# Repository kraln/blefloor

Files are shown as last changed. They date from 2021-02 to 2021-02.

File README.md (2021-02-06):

# BLEFloor

BLEFloor is an Arduino-powered WIFI/BLE connected thermostat 

## Warning

This hardware device is designed to switch/engage household voltages (100-230VAC). It has not been formally tested in any lab, nor does it carry any safety certification. While many precautions have been taken, always be careful around dangerous electricity as it is deadly and can kill you or others. In many jurisdictions, only electricians are allowed to connect to household voltages. Your mileage may vary, be careful!

## Hardware Description

The main controller is an Arduino Nano 33 IoT, which has an Atmel ARM Microcontroller attached to a uBlox Nina Wifi/BLE module (itself an ESP of some sort). A SI7020-A20 temperature/humidity sensor from Silicon Labs is attached, as well as a TPL5010 watchdog. The powersupply is a monolithic block from RECOM, the relay is from Omron, and the power path is fused and tranzorbed. 

### Theory of operation

A heated floor is controlled by a wax valve which melts over five minutes in the presence of heat. A heated floor thermostat is a bimetallic strip which can engage or disengage at a specific temperature. This device replaces the bimetallic strip with connected logic, such that it can be configured on a schedule, controlled remotely, make reports, etc. 

### Pictures

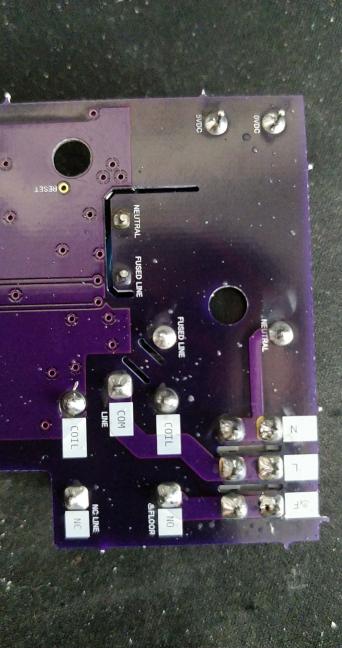
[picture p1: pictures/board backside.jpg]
Board Backside

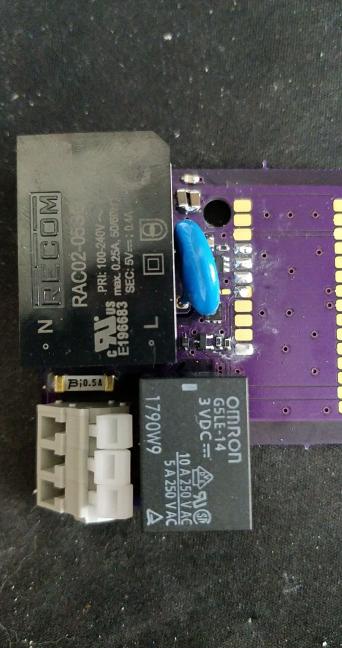
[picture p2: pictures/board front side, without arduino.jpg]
Board Front, No Arduino


### Errata

The temperature sensor is not sufficiently isolated from the operating conditions of the board and as such when the relay is engaged it senses a 2-3 degree self-warming. This is currently compensated for in the firmware.

## Firmware description

The firmware is written using a recent Arduino IDE. 

The setup() function initializes the GPIO pins, sets up an interrupt handler for the watchdog, sets up I2C for the temperature sensor, and initializes communications with the NINA module.

Configuration settings are saved in a file on the NINA module, this requires the firmware on the NINA module to be updated to a recent release (tested with 1.4.3). The contents of the configuration are in the settings_t struct. The first-run defaults are defined in the defaults() function.

The main loop() function checks to see if the watchdog chip activated, and if so reads the current temperature and humity. If configured, these values are reported to an InfluxDB UDP collector. The remote firmware update query is serviced, the HTTP handler is serviced, and the heartbeat LED is serviced.

If rip and rport are configured, the device will report the current temperature, relative humidity, if the relay is engaged, and when it has rebooted over UDP.

The HTTP handler listens for GET and POST requests. GET requests bring up a simple page with the current state of the device, whereas POST accepts the following commands in a query string:

| command | argument | comment |
| --- | --- | --- |
| ssid | wifi ssid to connect to | max length = 32 characters | 
| pass | password for wifi | max length = 32 characters |
| title | device name | max length = 32 characters |
| rip | reporting ip | address of influxdb in dotted format, max length 16 characters (though it should always fit in 13) | 
| rport | reporting port | port for influxdb udp |
| on | temperature in celcius below which the relay will engage | accepts numbers down to 5.0, anything beneath 5.0 will be raised to 5.0 |
| off | temperature in celcius above which the relay will disenage | accepts up to 50.0, anything above will be dropped to 50.0 |
| to | temperature offset | in case the reading differs from the actual room temperature, this will be applied before any other logic |
| save | n/a | instruct the thermostat to save the current configuration (must be last) |
| reset | n/a | instruct the thermostat to reboot | 
| relay | off/on | force the relay to (dis)engage |

Example Setting Config:

`   
  curl --data "ssid=My Access Point&pass=password!&rip=192.168.178.72&save=yes" 192.168.178.45
`  

### Pictures

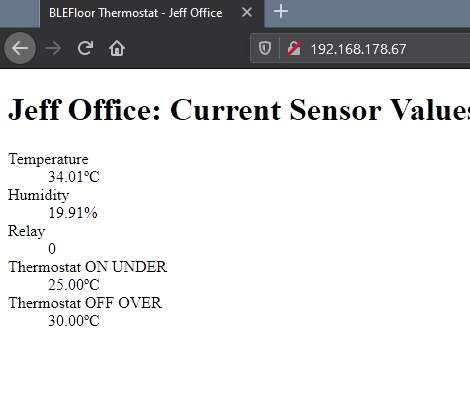
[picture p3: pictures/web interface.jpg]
Web Interface


### Errata

## Contributing
Pull requests are welcome. For major changes, please open an issue first to discuss what you would like to change.

## License
Firmware:
[MPLv2](https://choosealicense.com/licenses/mpl-2.0/)

Hardware design files:
[CC BY-SA 4.0](https://creativecommons.org/licenses/by-sa/4.0/)

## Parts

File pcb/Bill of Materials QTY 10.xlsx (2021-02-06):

Designator | Comment | Manufacturer 1 | Manufacturer Part Number 1 | Quantity | Supplier 1 | Supplier Part Number 1
C1, C2 | 4.7uF | Murata (https://octopart-clicks.com/click/altium?sku=81-GCM31CC71H475MA3K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) | GCM31CC71H475MA03K (https://octopart-clicks.com/click/altium?sku=81-GCM31CC71H475MA3K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) | 2 | Mouser | 81-GCM31CC71H475MA3K (https://octopart-clicks.com/click/altium?sku=81-GCM31CC71H475MA3K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) | 20
C3, C4, C5 | Cap Semi | Kyocera AVX (https://octopart-clicks.com/click/altium?sku=581-08055C104K4Z2A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) | 08055C104K4Z2A/4K (https://octopart-clicks.com/click/altium?sku=581-08055C104K4Z2A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) | 3 | Mouser | 581-08055C104K4Z2A (https://octopart-clicks.com/click/altium?sku=581-08055C104K4Z2A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) | 30
D1 | D Zener | Philips (https://octopart-clicks.com/click/altium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) | BZX384-B3V3,115 (https://octopart-clicks.com/click/altium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) | 1 | Mouser | 771-BZX384-B3V3-T/R (https://octopart-clicks.com/click/altium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) | 10
D2 | RELAY_EN | Stanley Electric (https://octopart-clicks.com/click/altium?manufacturer=Stanley%20Electric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) | SJW1151CKS-100-TR (https://octopart-clicks.com/click/altium?manufacturer=Stanley%20Electric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) | 1 | Mouser | 327-SJW1151CKS100TR (https://octopart-clicks.com/click/altium?manufacturer=Stanley%20Electric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) | 10
F1 | Fuse 1 | Bourns (https://octopart-clicks.com/click/altium?sku=652-SF-3812TL050T-2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) | SF-3812TL050T-2 (https://octopart-clicks.com/click/altium?sku=652-SF-3812TL050T-2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) | 1 | Mouser | 652-SF-3812TL050T-2 (https://octopart-clicks.com/click/altium?sku=652-SF-3812TL050T-2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) | 10
J1 | PTB Header | CUI Devices (https://octopart-clicks.com/click/altium?manufacturer=CUI%20Devices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) | TBL005A-500-03GY-2WT (https://octopart-clicks.com/click/altium?manufacturer=CUI%20Devices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) | 1 | Mouser | 490-TBL05A50003GY2WT (https://octopart-clicks.com/click/altium?manufacturer=CUI%20Devices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) | 10
K1 | Power Relay | Omron (https://octopart-clicks.com/click/altium?sku=653-G5LE-14DC3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) | G5LE-14-DC3 (https://octopart-clicks.com/click/altium?sku=653-G5LE-14DC3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) | 1 | Mouser | 653-G5LE-14DC3 (https://octopart-clicks.com/click/altium?sku=653-G5LE-14DC3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) | 10
MOV | Tranzorb | Bourns (https://octopart-clicks.com/click/altium?sku=652-MOV-14D391K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) | MOV-14D391K (https://octopart-clicks.com/click/altium?sku=652-MOV-14D391K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) | 1 | Mouser | 652-MOV-14D391K (https://octopart-clicks.com/click/altium?sku=652-MOV-14D391K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) | 10
Q1 | QNPN | Diodes (https://octopart-clicks.com/click/altium?sku=621-BC847A-7-F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) | BC847A-7-F (https://octopart-clicks.com/click/altium?sku=621-BC847A-7-F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) | 1 | Mouser | 621-BC847A-7-F (https://octopart-clicks.com/click/altium?sku=621-BC847A-7-F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) | 10
R1 | Res3 | Panasonic (https://octopart-clicks.com/click/altium?sku=667-ERJ-3EKF1001V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) | ERJ3EKF1001V (https://octopart-clicks.com/click/altium?sku=667-ERJ-3EKF1001V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) | 1 | Mouser | 667-ERJ-3EKF1001V (https://octopart-clicks.com/click/altium?sku=667-ERJ-3EKF1001V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) | 10
R2, R3, R4, R5 | Res3 | Panasonic (https://octopart-clicks.com/click/altium?sku=667-ERJ-3EKF1002V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) | ERJ-3EKF1002V (https://octopart-clicks.com/click/altium?sku=667-ERJ-3EKF1002V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) | 4 | Mouser | 667-ERJ-3EKF1002V (https://octopart-clicks.com/click/altium?sku=667-ERJ-3EKF1002V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) | 40
U0 | MCU | Arduino | Arduino Nano 33 IoT | 1 |  |  | 10
U1 | AC/DC 2W | Recom (https://octopart-clicks.com/click/altium?sku=919-RAC02-05SGA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) | RAC02-05SGA (https://octopart-clicks.com/click/altium?sku=919-RAC02-05SGA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) | 1 | Mouser | 919-RAC02-05SGA (https://octopart-clicks.com/click/altium?sku=919-RAC02-05SGA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) | 10
U2 | Watchdog | Texas Instruments (https://octopart-clicks.com/click/altium?sku=595-TPL5010DDCR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) | TPL5010DDCR (https://octopart-clicks.com/click/altium?sku=595-TPL5010DDCR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) | 1 | Mouser | 595-TPL5010DDCR (https://octopart-clicks.com/click/altium?sku=595-TPL5010DDCR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) | 10
U3 | Temp and Humidity Sensor | Silicon Labs (https://octopart-clicks.com/click/altium?sku=634-SI7020-A20-GM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) | SI7020-A20-GM (https://octopart-clicks.com/click/altium?sku=634-SI7020-A20-GM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) | 1 | Mouser | 634-SI7020-A20-GM (https://octopart-clicks.com/click/altium?sku=634-SI7020-A20-GM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) | 10

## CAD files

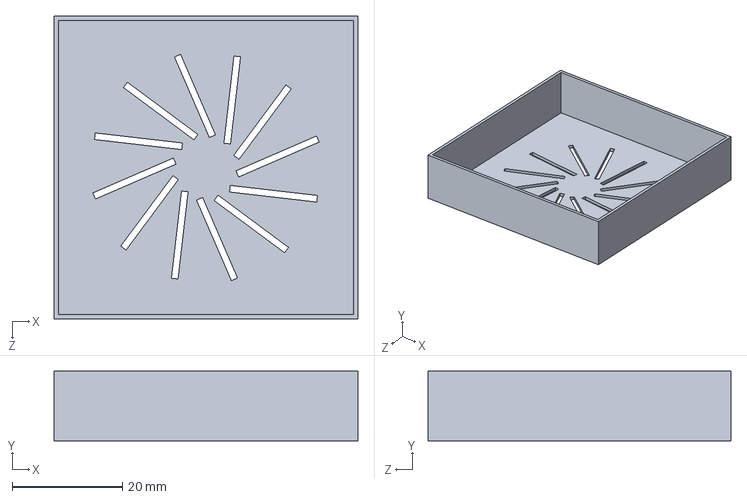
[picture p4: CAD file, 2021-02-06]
cover/Cover.SLDPRT
55.2 x 12.7 x 55.0 mm

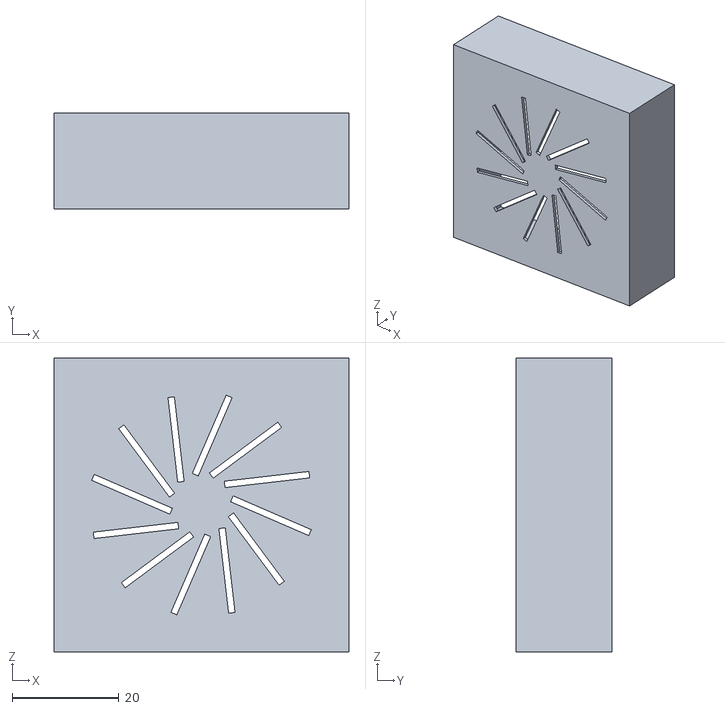
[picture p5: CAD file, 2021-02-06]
cover/Cover_Deep.STL
55.2 x 18.0 x 55.0

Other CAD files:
cover/Cover.STL

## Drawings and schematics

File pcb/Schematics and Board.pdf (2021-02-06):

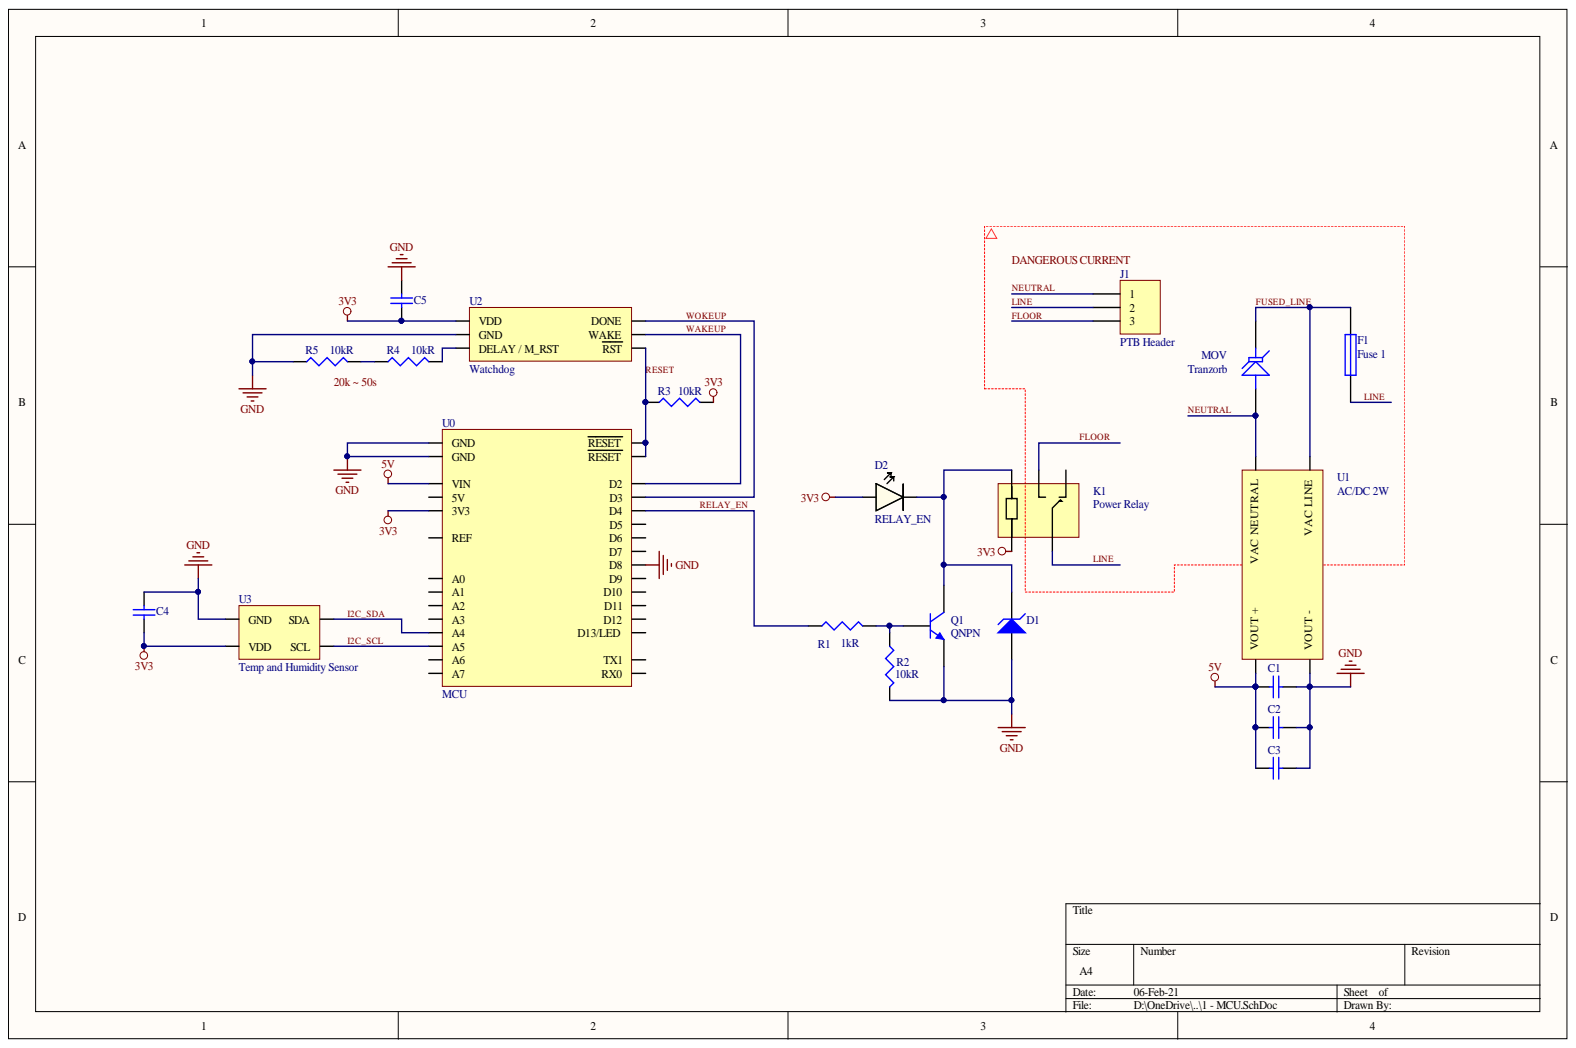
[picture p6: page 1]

S i z e | Nu mber | Rev i s i o n

0 6 -Feb -2 1 | Sheet o f

Fi le: D :\O neD ri ve\..\1 -M C U.Sch D o c | D raw n B y :

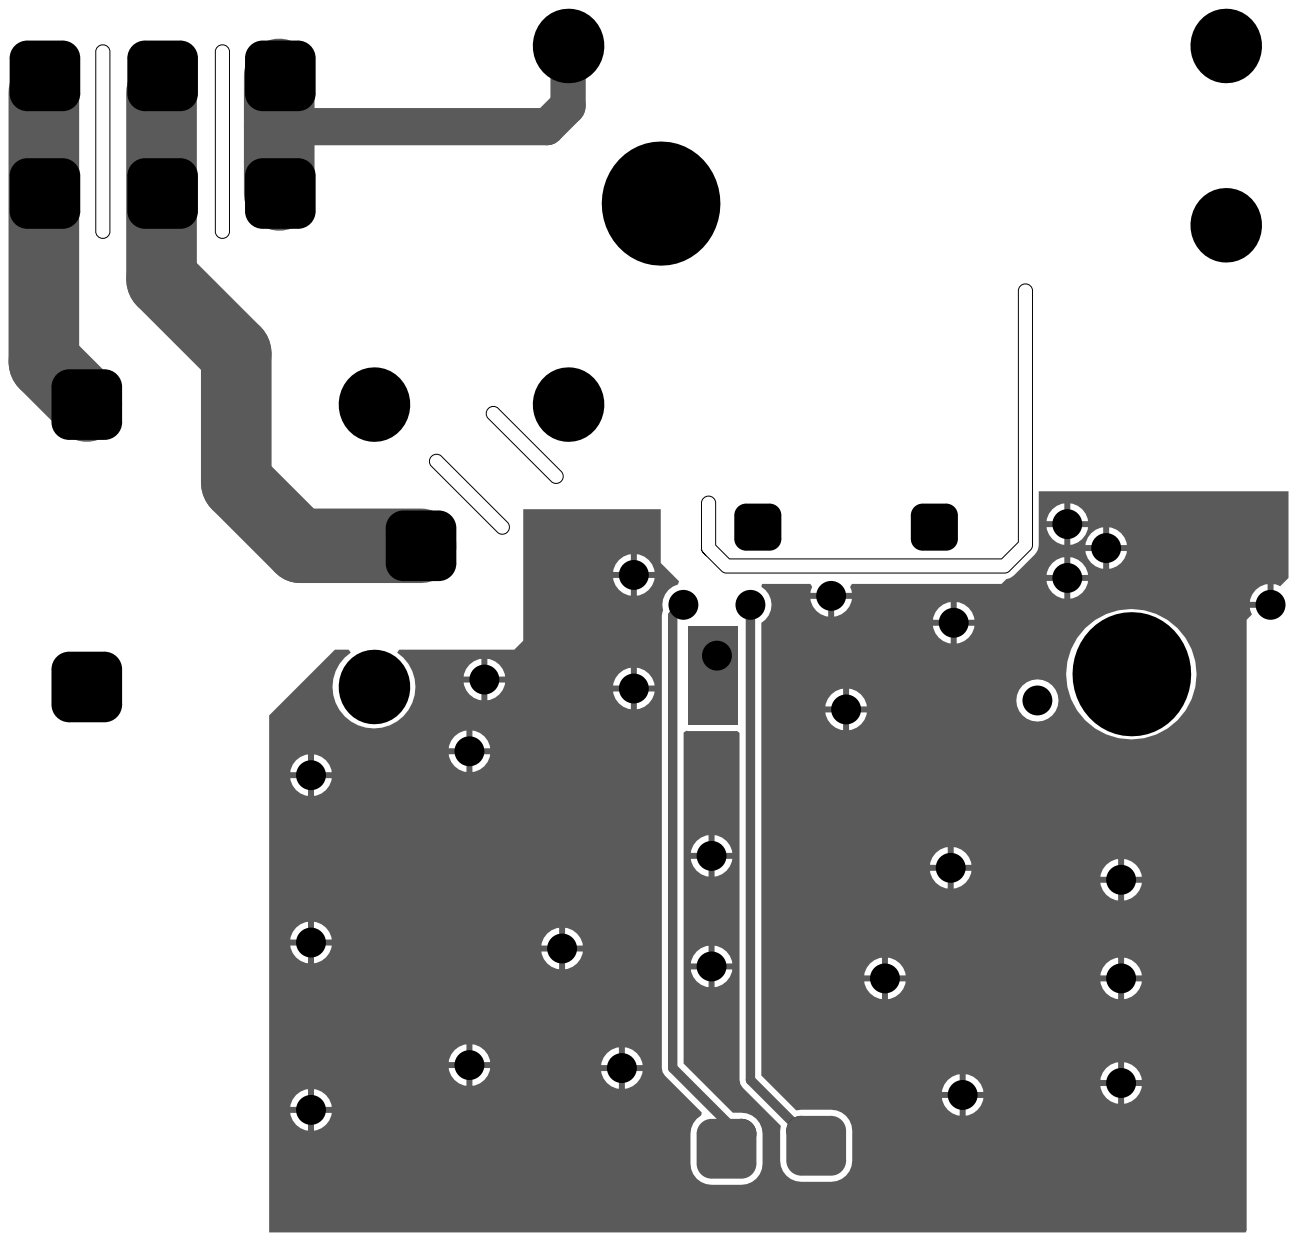
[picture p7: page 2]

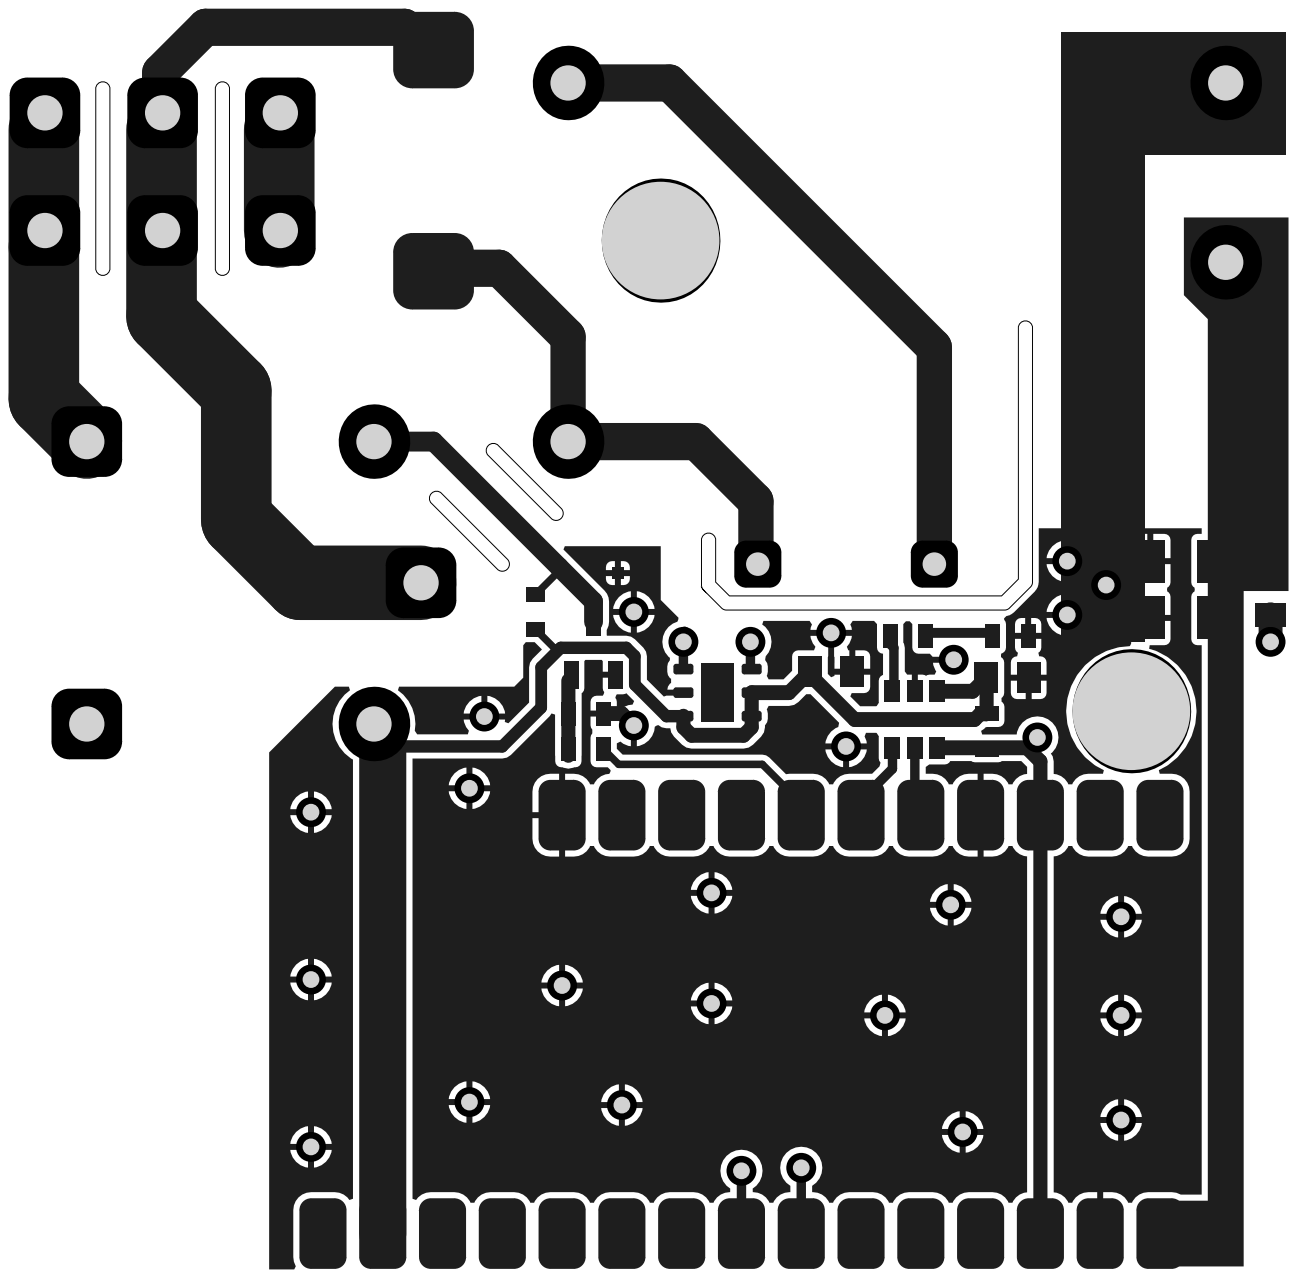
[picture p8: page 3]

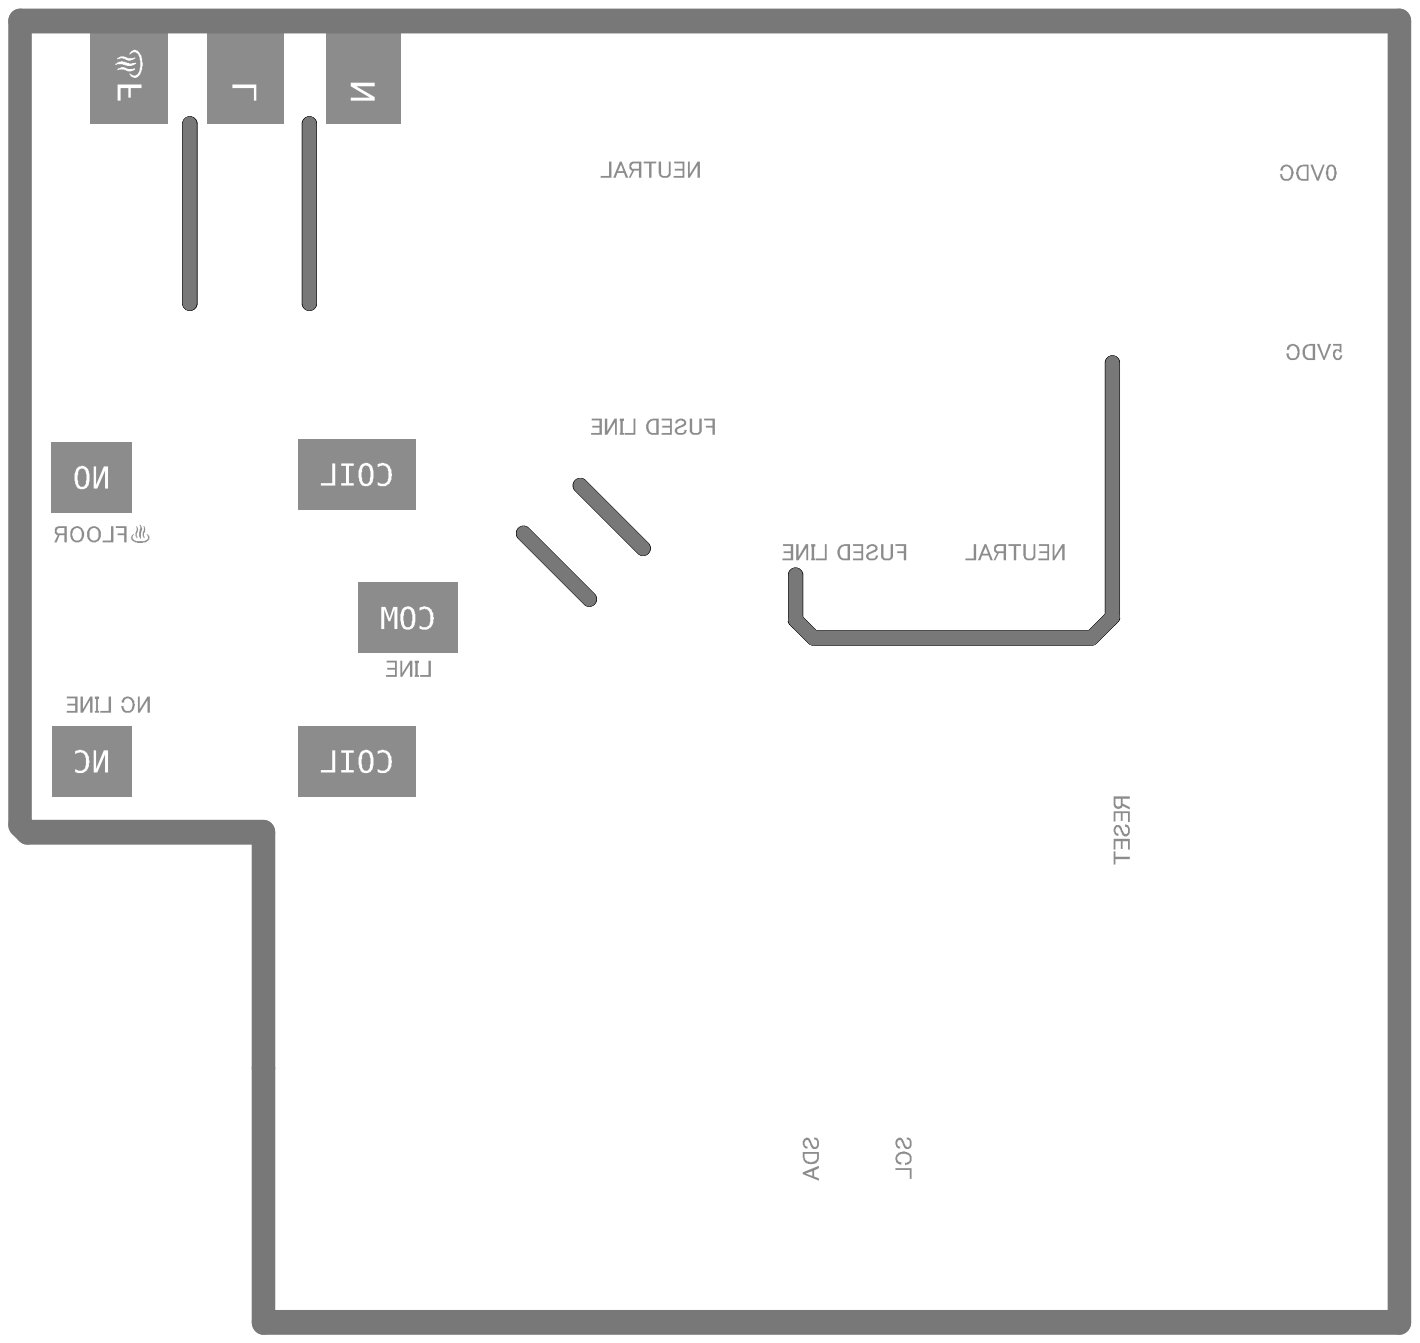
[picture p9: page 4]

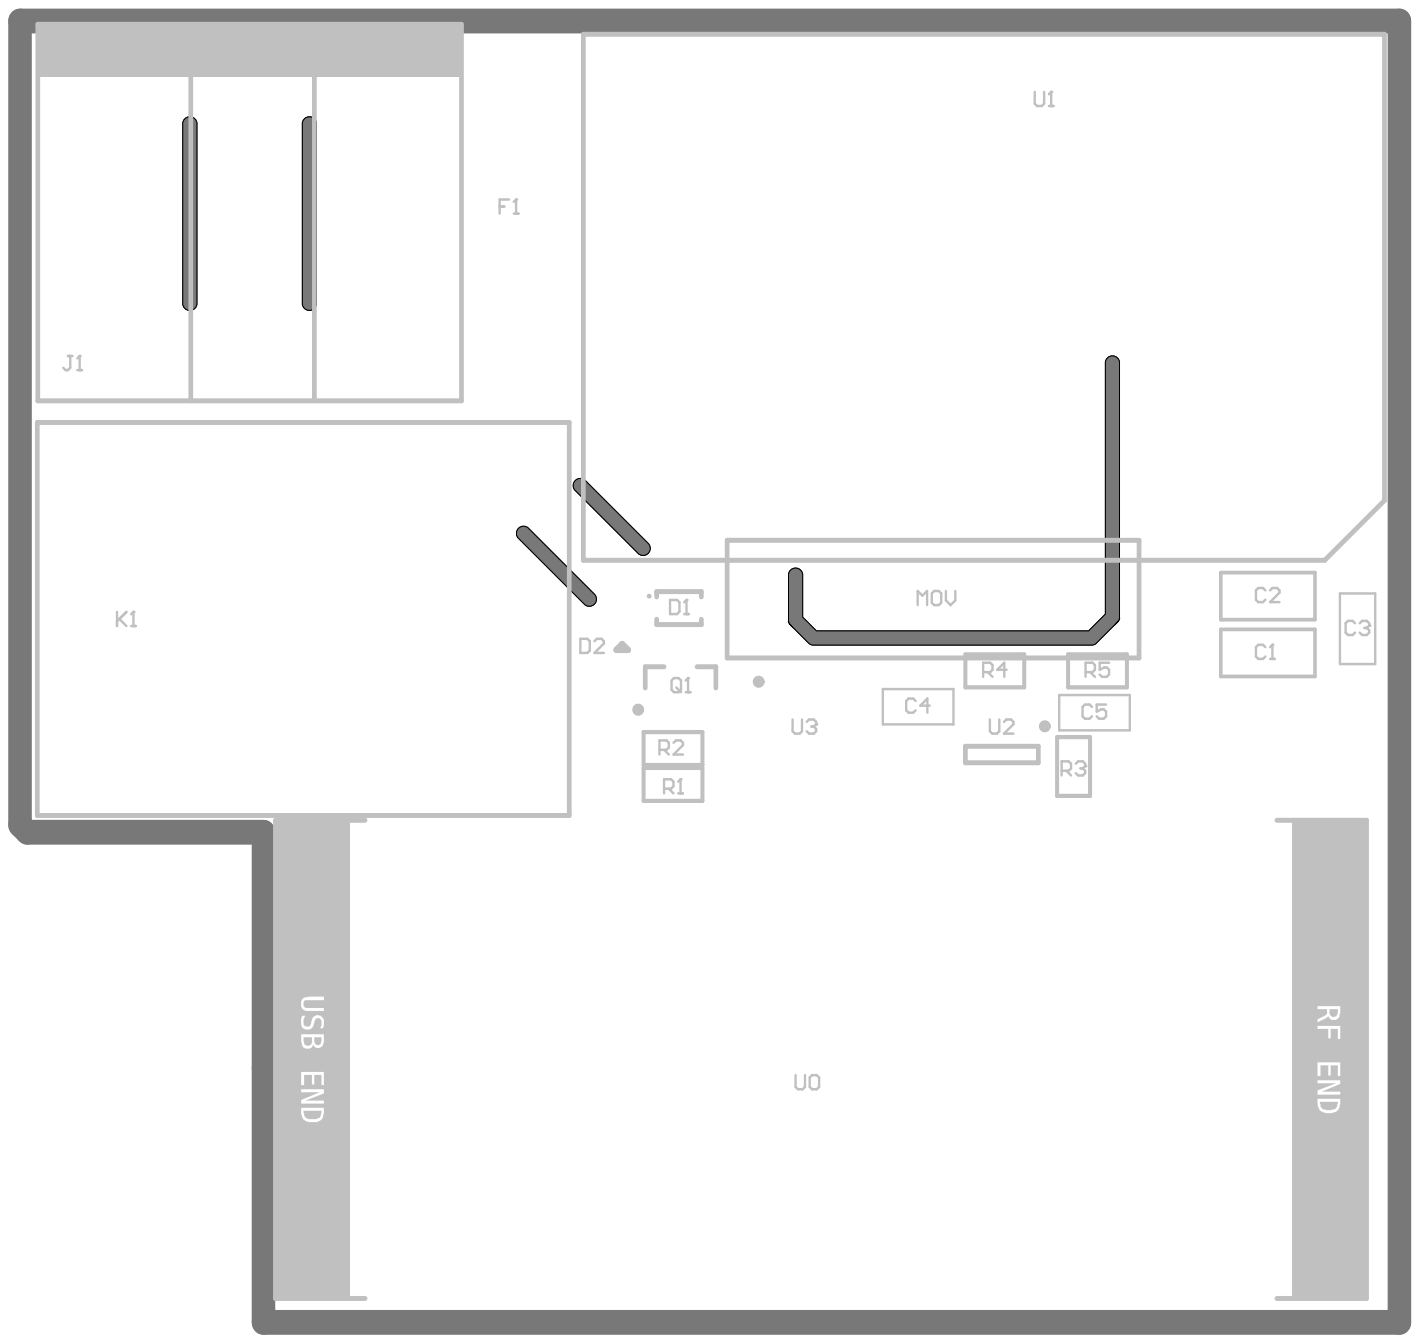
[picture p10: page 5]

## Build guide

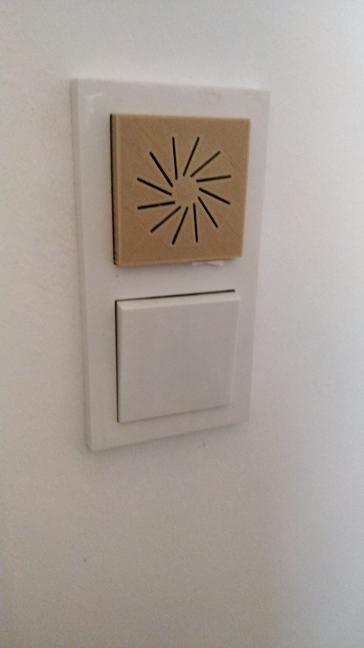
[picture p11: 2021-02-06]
pictures/installation with 3d-printed cover.jpg

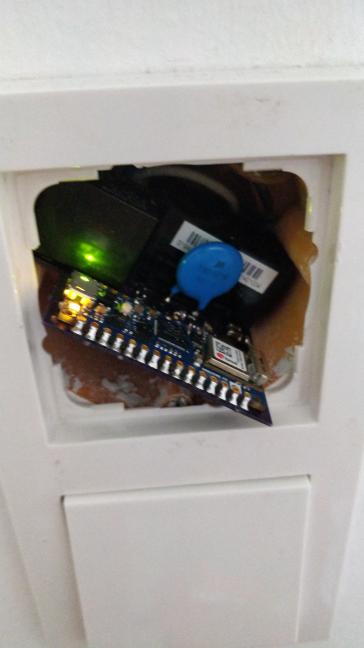
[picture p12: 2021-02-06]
pictures/installation in wall.jpg

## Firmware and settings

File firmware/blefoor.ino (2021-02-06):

#include <WiFiNINA.h>
#include <Wire.h>
#include <ArduinoOTA.h>

#define FILEPATH "/fs/testfile"

#define PIN_RELAY 4
#define PIN_WATCHDOG_OUT 3
#define PIN_WATCHDOG_IN 2

#define SI7020_ADDR 0x40

bool didBark = false;
bool hasWifi = true;

float last_temp = 0.0f;
float last_rh = 0.0f;

int oldRelayEnabled = LOW;
int relayEnabled = LOW;

/* wifi stuff */
int wifi_status = WL_IDLE_STATUS;
WiFiServer server(80);
WiFiUDP Udp;

typedef struct
{
  char wifi_ssid[32];
  char wifi_pass[32];
  char device_title[32];
  float on_under;
  float off_over;
  char report_ip[16];
  uint16_t report_port;
  float temp_offset;
} settings_t;

settings_t current_settings;

void setup()
{

  /* setup GPIO pins */
  pinMode(PIN_RELAY, OUTPUT);
  pinMode(LED_BUILTIN, OUTPUT);
  pinMode(PIN_WATCHDOG_IN, INPUT);
  pinMode(PIN_WATCHDOG_OUT, OUTPUT);

  /* Pin Interrupt */
  attachInterrupt(digitalPinToInterrupt(PIN_WATCHDOG_IN), watchDogBark, FALLING);

  /* Set up i2c */
  Wire.begin();

  /* Startup Debug */
  Serial.begin(9600);

  /* Reset sensor */
  Wire.beginTransmission(SI7020_ADDR);
  Wire.endTransmission();

  /* wait before printing the reset reason for the serial port to settle */
  delay(5000);

  if (WiFi.status() == WL_NO_MODULE) {
    Serial.println("Communication with WiFi module failed!");
    hasWifi = false;
  }

  if (hasWifi)
  {
    String fv = WiFi.firmwareVersion();
    if (fv < WIFI_FIRMWARE_LATEST_VERSION)
    {
      Serial.print("Your current firmware NINA FW v");
      Serial.println(fv);
      Serial.print("Please upgrade the firmware to NINA FW v");
      Serial.println(WIFI_FIRMWARE_LATEST_VERSION);
    }
  }
  /* Reset Reason */
  if (REG_PM_RCAUSE == 0b1000000)
  {
    Serial.println("Firmware updated / Soft Reset");
  }
  else
  {
    Serial.print("Device Reset (cause: 0b"); Serial.print(REG_PM_RCAUSE, BIN); Serial.println(")");
  }

  WiFiStorageFile file = WiFiStorage.open(FILEPATH);

  if (file)
  {
    if (file.size() == sizeof(settings_t))
    {
      file.read(&current_settings, sizeof(settings_t));
      Serial.println("Settings loaded:");
    }
    else
    {
      defaults();
    }
  }
  else
  {
    Serial.println("Error loading settings");
    defaults();
  }

  Serial.print("WIFI SSID:      "); Serial.println(current_settings.wifi_ssid);
  Serial.print("WIFI Pass:      "); Serial.println(current_settings.wifi_pass);
  Serial.print("Device Title:   "); Serial.println(current_settings.device_title);
  Serial.print("Engage Under:   "); Serial.println(current_settings.on_under);
  Serial.print("Disengage Over: "); Serial.println(current_settings.off_over);
  Serial.print("Reporting IP:   "); Serial.println(current_settings.report_ip);
  Serial.print("Reporting Port: "); Serial.println(current_settings.report_port);

  /* clear watchdog? */
  watchDogBark();

  if (hasWifi)
  {
    char buf[48] = "BLEFloor ";
    strncpy(&buf[9], current_settings.device_title, sizeof(current_settings.device_title));
    WiFi.setHostname(buf);

    uint8_t attempts_max = 30;
    
    /* connect to wifi */
    while (wifi_status != WL_CONNECTED && attempts_max--)
    {
      Serial.print("Attempting to connect to SSID: ");
      Serial.println(current_settings.wifi_ssid);
      wifi_status = WiFi.begin(current_settings.wifi_ssid, current_settings.wifi_pass);
      delay(5000);
    }

    if (attempts_max <= 0)
    {
      hasWifi = false;   
      Serial.println("WIFI timed out");   
    }
    else
    {
      server.begin();
      Serial.println("Connected.");
      Serial.print("SSID: ");
      Serial.println(WiFi.SSID());
  
      IPAddress ip = WiFi.localIP();
      Serial.print("IP Address: ");
      Serial.println(ip);
  
      long rssi = WiFi.RSSI();
      Serial.print("signal strength (RSSI):");
      Serial.print(rssi);
      Serial.println(" dBm");

      Udp.begin(31337);
      ArduinoOTA.begin(WiFi.localIP(), current_settings.device_title, "password", InternalStorage);
    }
  }
}
void defaults()
{
  strcpy(current_settings.wifi_ssid, "");
  strcpy(current_settings.wifi_pass, "");
  strcpy(current_settings.device_title, "Default");
  current_settings.on_under = 18.0f;
  current_settings.off_over = 25.0f;
  strcpy(current_settings.report_ip, "");
  current_settings.report_port = 8089;
  current_settings.temp_offset = 0.0f;
            
  update_settings();
  Serial.println("No settings available, setting defaults");
}
void update_settings()
{
  WiFiStorageFile file = WiFiStorage.open(FILEPATH);
  if (file)
  {
    file.erase();
  }
   
  file.write(&current_settings, sizeof(settings_t));
  file.close();
}
void watchDogBark()
{
  digitalWrite(PIN_WATCHDOG_OUT, HIGH);
  delay(2);
  digitalWrite(PIN_WATCHDOG_OUT, LOW);
  didBark = true;
}

float readHumidity()
{
  uint8_t data[2];
  Wire.beginTransmission(SI7020_ADDR);
  Wire.write(0xF5); /* read humity, no hold, master */
  Wire.endTransmission();

  delay(150); /* properly is pinging until no longer NACKs */

  Wire.requestFrom(SI7020_ADDR, 2);

  if (Wire.available() == 2)
  {
    data[0] = Wire.read();
    data[1] = Wire.read();
  }

  float humidity  = ((data[0] * 256.0) + data[1]);
  return (((125 * humidity) / 65536.0) - 6);
}

float readTemp()
{
  uint8_t data[2];
  Wire.beginTransmission(SI7020_ADDR);
  Wire.write(0xF3); /* read temp, no hold, master */
  Wire.endTransmission();

  delay(150); /* properly is pinging until no longer NACKs */

  Wire.requestFrom(SI7020_ADDR, 2);

  if (Wire.available() == 2)
  {
    data[0] = Wire.read();
    data[1] = Wire.read();
  }

  float temp  = ((data[0] * 256.0) + data[1]);
  return (((175.72 * temp) / 65536.0) - 46.85) + current_settings.temp_offset + (relayEnabled == HIGH ? -2.5f : 0.0f); // self-heating due to relay coil
}

void setRelay(int state)
{
  if (state == HIGH)
  {
    Serial.println("Relay Engaging");
  }
  else
  {
    Serial.println("Relay Disengaging");
  }

  digitalWrite(PIN_RELAY, state);
  digitalWrite(LED_BUILTIN, state);
}

void setConfig(char* key, char* val)
{
  bool updated = false;
  if (!strncmp(key, "ssid", 4))
  {
    strcpy(current_settings.wifi_ssid, val);
    updated = true;
    Serial.println("Updated SSID");
  }
  if (!strncmp(key, "pass", 4))
  {
    strcpy(current_settings.wifi_pass, val);
    updated = true;
    Serial.println("Updated Password");
  }
  if (!strncmp(key, "title", 5))
  {
    strcpy(current_settings.device_title, val);
    char buf[48] = "BLEFloor ";
    strncpy(&buf[9], current_settings.device_title, sizeof(current_settings.device_title));
    WiFi.setHostname(buf);
    updated = true;
    Serial.println("Updated Title");
  }

  if (!strncmp(key, "rip", 3))
  {
    strncpy(current_settings.report_ip, val, 16);
    updated = true;
    Serial.println("Updated Reporting IP");
  }

  if (!strncmp(key, "rport", 5))
  {
    current_settings.report_port = atoi(val);
    updated = true;
    Serial.println("Updated Reporting Port");
  }
  
  if (!strncmp(key, "on", 2))
  {
    current_settings.on_under = strtof(val, NULL);  
    if (current_settings.on_under < 5.0f)
    {
      current_settings.on_under = 5.0f;
    }
    updated = true;
    Serial.println("Updated Thermostat ON");
  }
  if (!strncmp(key, "to", 3))
  {    
    current_settings.temp_offset = strtof(val, NULL);  
    updated = true;
    Serial.println("Updated Thermostat Temp Offset");
  }
     
  if (!strncmp(key, "off", 3))
  {
    current_settings.off_over = strtof(val, NULL);  
    if (current_settings.off_over > 50.0f)
    {
      current_settings.off_over = 50.0f;
    }
    updated = true;
    Serial.println("Updated Thermostat OFF");
  }
  
  if (!strncmp(key, "save", 4))
  {
    Serial.println("Saving Config...");
    update_settings();
    updated = true;
  }

  if (!strncmp(key, "reboot", 6))
  {
    Serial.println("Rebooting");
    NVIC_SystemReset();
  }

  if (!strncmp(key, "relay", 5))
  {
    if (!strncmp(val, "on", 2))
    {
      relayEnabled = HIGH;
    } 
    else
    {
      relayEnabled = LOW;
    }
    updated = true;
    Serial.print("Set relay: "); Serial.println(relayEnabled);
  }
  
  if (!updated)
  {
    Serial.print("Unknown Key: "); Serial.println(key);
  }  
}

void handleHttp()
{
  if (!hasWifi) return;
  
  bool firstChar = true;
  bool isGet = false;
  bool isPost = false;
  WiFiClient client = server.available();
  if (client)
  {
    Serial.println("new request");
    // an http request ends with a blank line
    boolean currentLineIsBlank = true;
    while (client.connected())
    {
      if (client.available())
      {
        char c = client.read();

        if (firstChar)
        {
          firstChar = false;

          if (c == 'G')
          {
            Serial.println("GET request");
            isGet = true;
          }

          if (c == 'P')
          {
            Serial.println("POST or PUT request");
            isPost = true;
          }
        }
        Serial.write(c);
        if (c == '\n' && currentLineIsBlank)
        {
          if (isGet)
          {
            // send a standard http response header
            client.println("HTTP/1.1 200 OK");
            client.println("Content-Type: text/html");
            client.println("Connection: close");
            client.println("Refresh: 30"); 
            client.println();
            client.println("<!DOCTYPE HTML>");
            client.print("<html><head><meta charset=\"UTF-8\"><title>BLEFloor Thermostat - ");
            client.print(current_settings.device_title);
            client.println("</title></head><body>");
            client.print("<h1>"); client.print(current_settings.device_title); client.println(": Current Sensor Values</h1>");
            client.println("<dl>");
            client.println("<dt>Temperature</dt>");
            client.print("<dd>"); client.print(last_temp); client.print("ºC</dd>");
            client.println("<dt>Humidity</dt>");
            client.print("<dd>"); client.print(last_rh); client.print("%</dd>");
            client.println("<dt>Relay</dt>");
            client.print("<dd>"); client.print(relayEnabled); client.print("</dd>");
            client.println("<dt>Thermostat ON UNDER</dt>");
            client.print("<dd>"); client.print(current_settings.on_under); client.print("ºC</dd>");
            client.println("<dt>Thermostat OFF OVER</dt>");
            client.print("<dd>"); client.print(current_settings.off_over); client.print("ºC</dd>");            
            client.println("</dl>");
          }

          if (isPost)
          {
            char buf[1000];
            uint16_t bufidx = 0;
            memset(buf, 0, 1000);
            
            while(client.available() && bufidx < 1000)
            {
              buf[bufidx++] = client.read();                            
            }
            //Serial.println("POST/PUT Content:");
            //Serial.println(buf);
        
            client.println("HTTP/1.1 200 OK");
            client.println("Content-Type: text/html");
            client.println("Connection: close");  // the connection will be closed after completion of the response
            client.println();
            client.println("OK");
            
            char* token;
            char* rest;
            token = strtok_r(buf, "&", &rest);
            do 
            {
              char* key;
              char* val;
              char* rst;
              //Serial.print("Token: ");
              //Serial.println(token);    

              key = strtok_r(token, "=", &rst);
              //Serial.print("Key: "); Serial.println(tok);
              val = strtok_r(NULL, "=", &rst);
              //Serial.print("Value: "); Serial.println(tok);              
              setConfig(key, val);
              
            } while ((token = strtok_r(NULL, "&", &rest)));
          }
          break;
        }
        if (c == '\n') {
          currentLineIsBlank = true;
        } else if (c != '\r') {
          currentLineIsBlank = false;
        }
      }
    }
    delay(1);

    client.stop();
    Serial.println("request complete");
  }
}

void handleWIFI()
{
   if (!hasWifi) return;
   int status = WiFi.status();
   if (status==WL_DISCONNECTED || status==WL_CONNECTION_LOST)
   {
    Serial.println("WIFI disconnected, reconnecting...");
     
    uint8_t retry_count = 30;
    while (status != WL_CONNECTED && retry_count--)
    {
      status = WiFi.begin(current_settings.wifi_ssid, current_settings.wifi_pass);
      delay(5000);
    }  

    if (retry_count > 0)
    {
      Serial.println("WIFI Re-Connected.");
      Serial.print("SSID: ");
      Serial.println(WiFi.SSID());
  
      IPAddress ip = WiFi.localIP();
      Serial.print("IP Address: ");
      Serial.println(ip);
  
      long rssi = WiFi.RSSI();
      Serial.print("signal strength (RSSI):");
      Serial.print(rssi);
      Serial.println(" dBm");
      Udp.stop();
      Udp.begin(31337);
    }
    else
    {
      Serial.println("WIFI Failed");
      WiFi.end();   
      WiFi.disconnect();
    }
  }
}

char* dev_title_escaped(char* buf)
{
  
  strncpy(buf, current_settings.device_title,32);
  for (uint8_t i = 0; i < strlen(buf); i++)
  {
    if (buf[i] == ' ')
    {
      buf[i] = '-';
    }
  }
  return buf;
}

bool rebooted = true;

void handleReport()
{ 
  if (!hasWifi) return;

  char buf[255] = { 0 };
  char buf2[32] = { 0 };
  strcpy(buf, "report,device=");
  strcpy(&buf[strlen(buf)], dev_title_escaped(buf2));

  uint8_t start = strlen(buf);  
  sprintf(&buf[start], " temp=%f         ", last_temp);
  
  bool attempt = Udp.beginPacket(current_settings.report_ip, current_settings.report_port);  
  if (attempt)
  {
    Serial.println(buf);
    Udp.write(buf);
    Udp.endPacket();
  } 
  else 
  {
    Serial.println("Error making temp report.");  
  }


  sprintf(&buf[start], " rh=%f          ", last_rh);
  attempt = Udp.beginPacket(current_settings.report_ip, current_settings.report_port);  
  if (attempt)
  {
    Serial.println(buf);
    Udp.write(buf);
    Udp.endPacket();
  } 
  else 
  {
    Serial.println("Error making humidity report.");  
  }

  sprintf(&buf[start], " relay=%d          ", relayEnabled);
  attempt = Udp.beginPacket(current_settings.report_ip, current_settings.report_port);  
  if (attempt)
  {
    Serial.println(buf);
    Udp.write(buf);
    Udp.endPacket();
  } 
  else 
  {
    Serial.println("Error making relay report.");  
  }

  if (rebooted)
  {
    rebooted = false;
    sprintf(&buf[start], " rebooted=1          ");
    attempt = Udp.beginPacket(current_settings.report_ip, current_settings.report_port);  
    if (attempt)
    {
      Serial.println(buf);
      Udp.write(buf);
      Udp.endPacket();
    } 
    else 
    {
      Serial.println("Error making relay report.");  
    }
  }
}

void loop()
{
  if (didBark)
  {
    didBark = false;

    last_temp = readTemp();
    last_rh = readHumidity();

    if (current_settings.on_under > current_settings.off_over)
    {
      Serial.println("Invalid temperature settings, ignoring");
    }
    else
    {
      if (last_temp <= current_settings.on_under && relayEnabled != HIGH)
      {
        relayEnabled = HIGH;
      }

      if (last_temp >= current_settings.off_over && relayEnabled != LOW)
      {
        relayEnabled = LOW;
      }
    }

    handleWIFI();
    handleReport();
    
    Serial.println("Watchdog:       Woof");
    Serial.print("Temperature:    "); Serial.print(last_temp); Serial.println("'C");
    Serial.print("Humidity:       "); Serial.print(last_rh); Serial.println("%");
    Serial.print("Relay:          "); Serial.println(relayEnabled);
    Serial.print("Thermostat ON:  Under "); Serial.print(current_settings.on_under); Serial.println("'C");
    Serial.print("Thermostat Off: Over "); Serial.print(current_settings.off_over); Serial.println("'C");
  }

  handleHttp();
  if (hasWifi)
  {
    ArduinoOTA.poll();
  } 
 
  if (oldRelayEnabled != relayEnabled)
  {
    oldRelayEnabled = relayEnabled;
    setRelay(relayEnabled);
  }

  digitalWrite(LED_BUILTIN, relayEnabled);  
  delay(50);
  digitalWrite(LED_BUILTIN, !relayEnabled);  
  delay(20);
  digitalWrite(LED_BUILTIN, relayEnabled);  
  delay(50);
}
